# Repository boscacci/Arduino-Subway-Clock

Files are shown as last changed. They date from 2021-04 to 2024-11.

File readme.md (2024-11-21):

# You're about to make your own MTA clock!

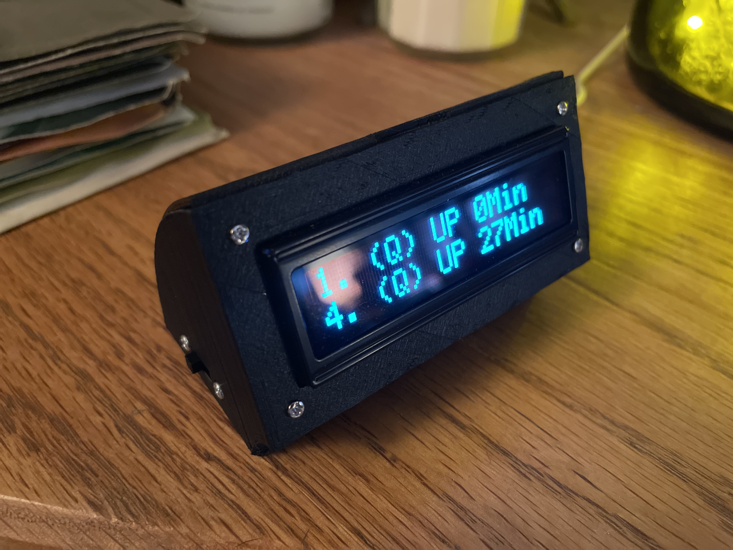
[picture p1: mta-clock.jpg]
Esp32 MTA Clock


Here's how to do it:
1. Host a server (to translate the complex MTA API into something more RESTful).
2. Put and run MTA API code on the server.
3. Buy parts.
4. Wire it up.
5. Install some software.
6. Set up your Arduino project.
7. Edit your MTA Clock preferences.
8. Compile and upload the code.
9. Make an enclosure.
10. Assemble.
11. Don't miss your train!

# 1. Host a server.

  * Recommended: Launch a cloud linux instance, e.g. Ubuntu on AWS. (More [verbose instructions here](https://docs.aws.amazon.com/AWSEC2/latest/UserGuide/EC2_GetStarted.html])
  * Configure the instance's network (and security) settings such that it can respond to requests from wherever the subway clock will be.
  * Connect to your server over SSH.
      
# 3. Put and run MTA API code on the server.

  * Put the MTA API code on the server by cloning from git repo.
  * Use this command in terminal while controlling your server: `git clone https://github.com/jonthornton/MTAPI`
  * cd into the repo top-level directory: `cd MTAPI/`
  * Update your Ubuntu server so it can install stuff: `sudo apt-get update && sudo apt-get upgrade`
  * Install python on your server: `sudo apt-get install python3-venv`
  * Create a new python virtual environment: `python3 -m venv .venv`
  * Create a new tmux session (allowing the code to run unattended): `tmux new -s session-name`
  * Activate the virtual environment: `source .venv/bin/activate`
  * Install necessary python libraries: `pip install -r requirements.txt`
  * Launch the service and begin listening for requests: `python app.py`
  * Detach from the tmux session: ctrl-b, then press d key
  * Disconnect from the ec2 server: `logout`
  * It should be running on its own now!

# 4. Buy parts.

  These are the parts you will need and some examples of where to find them:
  * ESP32 Dev Board (any ESP dev board will do) - https://www.amazon.com/HiLetgo-ESP-WROOM-32-Development-Microcontroller-Integrated/dp/B0718T232Z
  
  * LCD Screen (16x2 Character Display)- https://www.adafruit.com/product/823 - if they're not available through adafruit, try amazon or aliexpress for other 'standard' HD44780 1602 LCDs.
  
  * On/Off Switch (this is just the one we used) - https://www.amazon.com/Qiying-Miniature-SS-12F16-Position-Latching/dp/B08947137H
  
  * Jumperwires
  
  * USB Cable

  Total cost estimate: ~$50-80 depending on parts availability

# 5. Wire it up.

  __Adafruit OLED Wiring Guide:__

  | OLED pin    | ESP32 pin     |
  | :------------- | :------------- |
  |  1 (gnd)    |     GND         |
  |  2 (vin)    |     VIN         |
  |  4 (rs)     |     14          |
  |  5 (rw)     |     32          |
  |  6 (en)     |     26          |
  | 11 (d4)     |     33          |
  | 12 (d5)     |     27          |
  | 13 (d6)     |     12          |
  | 14 (d7)     |     13          |

   * If your ESP32 has different pins labeled, feel free to swap out pins per this pinout guide, but also update line 24 `Adafruit_CharacterOLED lcd(OLED_V2, 14, 32, 26, 33, 27, 12, 13);` in the mta_clock.ino accordingly: https://randomnerdtutorials.com/esp32-pinout-reference-gpios/

   * Optional: Connect, an on/off switch between ESP32 pin 25 (or any other digital pin) and GND.

# 6. Install some software.

## 6.1 Install ArduinoIDE.

  * Download and install the ArduinoIDE from here: https://www.arduino.cc/en/software

## 6.2 Install ESP board in Arduino.

  * Open ArduinoIDE
  * Copy the URL found at this git: https://github.com/espressif/arduino-esp32/blob/master/docs/arduino-ide/boards_manager.md
  * In ArduinoIDE, paste to File > Preferences > Additional Board Manager URLs
  * Open Boards Manager from Tools > Board menu
  * Search for "esp32" and Install
  * Select your particular ESP32 board from Tools > Board menu

## 6.3 Install necessary libraries.

  * Open Library Manager from Tools > Manage Libraries...
  * Search for "Arduino_JSON" and Install
  * Download ZIP from here: https://github.com/ladyada/Adafruit_CharacterOLED
  * Add the library to Arduino from Sketch > Include Library > Add .ZIP Library...

# 7. Set up your Arduino project.

  * If you haven't already, download the ZIP of this Git Repo.
  * Move the folder "mta_clock" from the ZIP folder into your Sketchbook folder.
  * If you don't know where that is, it is listed at File > Preferences > Sketchbook location

# 8. Edit your MTA Clock preferences.

  * Open the mta_clock.ino sketch from File > Sketchbook > mta_clock
  * Go to the preferences.h tab.
  * Replace the default with your Wifi network info, server IP (found in your EC2 instances, use the IPv4 address), and other preferred settings. [You can find the codes for StationID's here](https://github.com/boscacci/MTAPI/blob/master/data/stations.json).
  * Save your changes.

# 9. Compile and upload the code.

  * Connect the ESP32 to the computer with the USB cable.
  * Ensure that the correct port is selected at Tools > Port > /dev/cu.usbserial*
  * Ensure that Tools > Upload Speed is set to 115200
  * Click the check mark to "Verify" (a.k.a. Compile) the code.
  * Click the => to upload the code to your ESP32.
  * Wait.... this will probably take a minute or two.
  * When it's done uploading, you can open the Serial monitor (set to Baud rate: 115200) with the magnifying glass button to see how it's doing.

  NOTE: For some reason, the LCD might not display properly while the serial monitor window is open.

  ANOTHER NOTE: The LCD won't reset when the ESP32 resets, so you might have to unplug and replug the usb cable to get it to display properly.

# 10. Make an enclosure.

  * You can buy something like this: https://www.amazon.com/CANADUINO-Character-Display-Acrylic-Enclosure/dp/B07C4XWX21

  NOTE: It did not fit my display and there isn't a great way to mount the ESP32.

  * Alternatively, you can 3D print the enclosure found in the git.
    To avoid supports:
    * Print main_enclosure_switch.stl or main_enclosure_noswitch.stl lcd-face down
    * Print enclosure_cover.stl on one end - the little tabs are tapered on one edge more than the other and that should face down.

# 11. Assemble.

  If you're happy with your preferences, and everything fits properly in the enclosure, you can solder the connections and install everything in the enclosure.

# 12. Don't miss your train!

  If you're still reading, thanks for reading me. Now, credit where credit is due! Thanks to:

  Zach Kuperstein for toiling in an unfamiliar language to make this, and making the instructions as clear as possible!

  Jon Thornton for making the MTA's GTFS protobuf accessible.

  Bill & George at NYC Resistor for making the first generation version of this.

  The MTA for making its data available to the public.

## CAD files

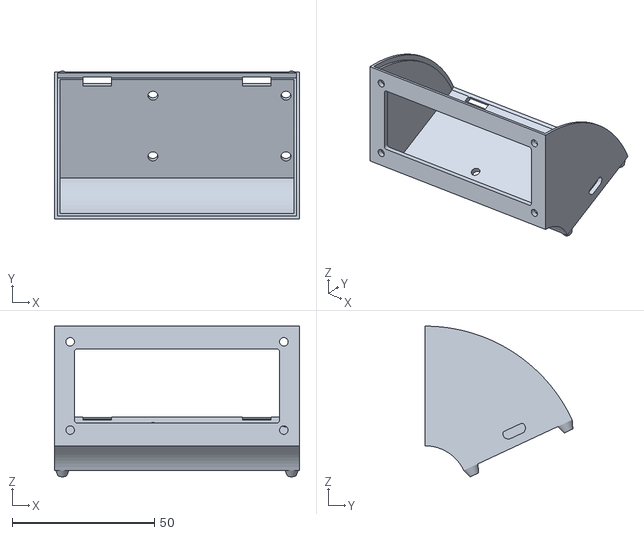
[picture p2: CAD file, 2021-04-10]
3d print files/main_enclosure_noswtich.stl
86.0 x 51.9 x 52.9

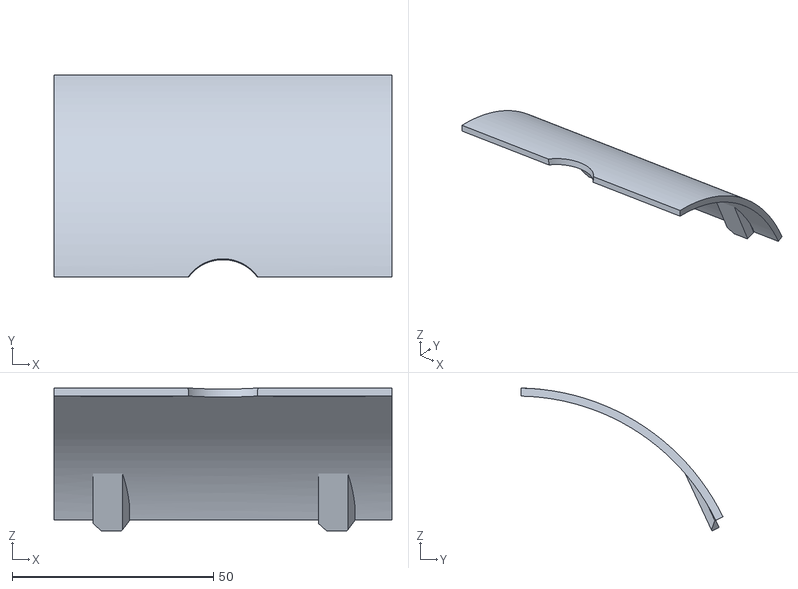
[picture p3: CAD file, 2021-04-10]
3d print files/enclosure_cover.stl
84.0 x 50.2 x 35.5

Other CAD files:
3d print files/main_enclosure_switch.stl

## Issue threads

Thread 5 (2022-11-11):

This is not an issue, just a question!

fixingthingsguy, 2022-11-11:
Hello Robert, Great job with the application. Not much of a modern techie, but wondering what the purpose of the AWS EC2 set  up was for.
Basically I'm wondering if the MTA feed can't be received at the ESP. There are other feeds, probably for sure not as complex, that ESP can receive, for example weather underground.
So I was looking to see if that kind of model would work.
Thanks, again, great job.
I'll delete this in a couple of days since its not a fair "issue:".
Regards

fixingthingsguy, 2022-11-27:
Not really an issue, so closing as promised.

boscacci, 2022-11-27:
Hi there, thanks for asking.

Programmers better than me have succeeded at parsing the MTA protobuf feed directly on the ESP32. I am not among their ranks.

Instead, here we used MTAPI (hosted on an ec2 instance, but could be hosted anywhere I guess) to translate the MTA protobuf feed into something more RESTful which the ESP32 could query more easily.

fixingthingsguy, 2022-11-29:
Hi Robert Thanks for rhe explanation. I had seen some  very complex approaches on the internet alluding to what you said.Anyway, I'm marching along the steps you provided . The ESP I'm familar with, and I think I can figure out the EC2 implementation, with a few attempts and re-do's.Thanks for taking the trouble to post your solution.

Sent from Yahoo Mail on Android

  On Sun, Nov 27, 2022 at 2:23 PM, Robert ***@***.***> wrote:

Hi there, thanks for asking.

Programmers better than me have succeeded at parsing the MTA protobuf feed directly on the ESP32. I am not among their ranks.

Instead, here we used MTAPI (hosted on an ec2 instance, but could be hosted anywhere I guess) to translate the MTA protobuf feed into something more RESTful which the ESP32 could query more easily.

—
Reply to this email directly, view it on GitHub, or unsubscribe.
You are receiving this because you modified the open/close state.Message ID: ***@***.***>

Closed 2022-11-27.

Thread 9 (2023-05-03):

Compilation error: 'JSONVar' was not declared in this scope

thagoober, 2023-05-03:
Hello,

I've followed your instructions and am really excited to have this working, it's been a fantastic beginner project for me to learn.

However, I'm struggling with this line of code that is producing an odd error I haven't been able to figure out.. Would you happen to have any insight why I'm getting this error on upload?

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

thagoober, 2023-05-03:
Nevermind, I've figured out there was a probem with the json library installation. Thanks!

Closed 2023-05-03.

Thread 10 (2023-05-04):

Watchdog timer issue with esp32?

thagoober, 2023-05-04:
I am having a hell of a time sorting through this one, and even had ChatGPT make some sense of this for me, but once I upload the code to the esp32, it gives me this message in the Output:

Leaving...
Hard resetting via RTS pin...

Followed by this recurring error (in 10s intervals) in the Serial Monitor (which looks like a watchdog timer issue due to a loop in the code):

rst:0x10 (RTCWDT_RTC_RESET),boot:0x13 (SPI_FAST_FLASH_BOOT)
configsip: 0, SPIWP:0xee
clk_drv:0x00,q_drv:0x00,d_drv:0x00,cs0_drv:0x00,hd_drv:0x00,wp_drv:0x00
mode:DIO, clock div:2
load:0x3fff0030,len:1344
load:0x40078000,len:13808
load:0x40080400,len:3608
entry 0x400805f0

May I ask your advice on this?

thagoober, 2023-05-04:
Holy smokes I figured it out.. I needed to connect a 3.3v + ground connection to the VSS/VDD side of the OLED, while also connecting 5v+ground as indicated. This solves the issue with the OLED loop in the code getting timed out by the watchdog timer.

boscacci, 2023-05-27:
Nicely done sorry for the delayed response

Closed 2023-05-04.

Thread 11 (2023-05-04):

Issue with OLED library

thagoober, 2023-05-04:
Be sure to change the entry in the OLED library from "void begin(uint8_t cols, uint8_t rows, uint8_t character_set = LCD_JAPANESE);" to "void begin(uint8_t cols, uint8_t rows, uint8_t character_set /*= LCD_JAPANESE*/);"

Needs /* */ or the code will not compile correctly in Arduino IDE.

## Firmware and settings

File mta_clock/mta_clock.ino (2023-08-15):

// include the library code:
#include <Adafruit_CharacterOLED.h>
#include <WiFi.h>
#include <HTTPClient.h>
#include <Arduino_JSON.h>
#include "time.h"
#include "preferences.h" //file containing User preferences

/*
  Adafruit OLED Wiring Guide (https://www.adafruit.com/product/823):

   OLED pin  <-->   ESP32 pin
    1 (gnd)         GND
    2 (vin)         VIN
    4 (rs)          14
    5 (rw)          32
    6 (en)          26
   11 (d4)          33
   12 (d5)          27
   13 (d6)          12
   14 (d7)          13

*/
Adafruit_CharacterOLED lcd(OLED_V2, 14, 32, 26, 33, 27, 12, 13);

#define SWITCH_PIN 25 // sets pin for direction toggle switch connect other end to GND

// This defines the direction variable differently depending on if you are using a toggle switch
#ifndef DIRECTION
char *direction = "N";
#else
const char *direction = DIRECTION;
#endif

// Declaring global variables
unsigned long lastRequestTime = 0;
unsigned long lastDisplayTime = 0;
time_t currentEpochTime;
struct tm currentTime;
char display[20];
char displayList[8][20];
byte listCount = 1;
bool forceRefresh = true;
bool switchState = true;
char url[sizeof(serverIP) + sizeof(stationID) + 19];
byte numberOfArrivals;

void setup()
{
  Serial.begin(115200);
  while (!Serial)
    ;

  Serial.println("Initializing...");

  // Sets up toggle switch pin with internal pullup resistor
  pinMode(SWITCH_PIN, INPUT_PULLUP);

  // Initialize the lcd
  Serial.print("LCD - ");
  lcd.begin(16, 2);
  Serial.println("LCD success!");

  // Connect to the WiFi network
  connectWifi();

  // Configure DST-aware datetime for NYC
  initTime("EST5EDT,M3.2.0,M11.1.0");

  Serial.print("Local time: ");
  printLocalTime();
  Serial.println(" - Success!");

  // Make url for MTA data request
  sprintf(url, "http://%s:8080/by-id/%s", serverIP, stationID);

  delay(1000);
  lcd.clear();
}

void loop()
{
// If you have a direction toggle switch this function handles it
#ifndef DIRECTION
  switchHandler();
#endif

  // Send an HTTP GET request every time interval
  if (forceRefresh || (millis() - lastRequestTime) > requestInterval)
  {

    // Check WiFi connection status
    if (WiFi.status() == WL_CONNECTED)
    {

      // gets current local time in epoch and tm format respectively
      time(&currentEpochTime);
      getLocalTime(&currentTime);

      // Make server request and parse into JSON object
      JSONVar obj = JSON.parse(httpGETRequest(url));

      // JSON.typeof(jsonVar) can be used to get the type of the var
      if (JSON.typeof(obj) == "undefined")
      {
        Serial.println("Parsing input failed!");
        return;
      }

      // Pulls out the relevant data as an JSONVar array
      JSONVar arrivalsArr = obj["data"][0][direction];
      numberOfArrivals = arrivalsArr.length();

      // Initiate a count of arrivals that will be missed per timeToStation
      byte missed = 0;

      // Clear the displayList
      memset(&displayList, 0, sizeof(displayList));

      // Iterates through each pending arrival
      for (byte i = 0; i < numberOfArrivals; i++)
      {

        // Extracts the name of the train for the given arrival
        String trainName = JSON.stringify(arrivalsArr[i]["route"]).substring(1, 2);

        // Extracts the arrival time of the train in epoch time

        // DEBUG
        // Serial.print("Arrival time stringified: ");
        // Serial.println(JSON.stringify(arrivalsArr[i]["time"]));

        long arrivalTime = convertToEpoch(JSON.stringify(arrivalsArr[i]["time"]));

        // Calculates how many minutes to arrival by comparing arrival time to current time
        int minutesAway = (arrivalTime - currentEpochTime) / 60;

        // Filters out trains that you can't possibly catch
        if (minutesAway >= timeToStation)
        {

          // Constructs the display string
          sprintf(display, "%d. (%s) %s %dMin", i + 1 - missed, trainName, (direction == "N") ? "UP" : "DN", minutesAway);
          Serial.println(display);

          // Adds the given arrival to the display list for the lcd
          strcpy(displayList[i - missed], display);
        }
        else
        {
          missed++; // increment count of missed trains per timeToStation
        }
      }

      // Display the next arriving train on the first line of the lcd
      lcd.setCursor(0, 0);
      lcd.print("                "); // needed to clear the first line
      lcd.setCursor(0, 0);
      lcd.print(displayList[0]);
    }
    else
    {
      Serial.println("WiFi Disconnected");
      delay(1000);
      connectWifi();
    }
    lastRequestTime = millis();
  }

  // Rotate the arrival displayed on the second line at specified time interval
  if (forceRefresh || (millis() - lastDisplayTime) > displayInterval)
  {

    lcd.setCursor(0, 1);
    lcd.print("                "); // needed to clear the line if the previous display was longer
    lcd.setCursor(0, 1);
    lcd.print(displayList[listCount]);

    listCount++;
    if (listCount > moreArrivals || listCount >= numberOfArrivals)
      listCount = 1;

    lastDisplayTime = millis();

    forceRefresh = false;
  }
}

void connectWifi()
{
  Serial.print("Connecting to Wifi: ");
  Serial.print(ssid);

  lcd.clear();
  lcd.setCursor(0, 0);
  lcd.print("Joining Wifi");
  lcd.setCursor(0, 1);
  lcd.print(ssid);

  WiFi.begin(ssid, password);

  while (WiFi.status() != WL_CONNECTED)
  {
    delay(500);
    Serial.print(".");
    lcd.print(".");
  }

  lcd.setCursor(0, 0);
  lcd.print("Connected to:");
  Serial.println("Success!");
  Serial.print("IP address: ");
  Serial.println(WiFi.localIP());
}

String httpGETRequest(char *_url)
{
  HTTPClient http;

  Serial.print("Pinging: ");
  Serial.println(_url);

  // Connect to server url
  http.begin(_url);

  // Send HTTP GET request
  byte httpResponseCode = http.GET();

  if (httpResponseCode == 200)
  {
    Serial.print("Updated: ");
    Serial.println(&currentTime);
    return http.getString();
  }
  else
  {
    Serial.print("HTTP Error code: ");
    Serial.println(httpResponseCode);

    lcd.clear();
    lcd.setCursor(0, 0);
    lcd.print("HTTP ERROR: ");
    lcd.print(httpResponseCode);
    lcd.setCursor(0, 1);
    lcd.print("SERVER DOWN");
    delay(1000);
  }
}

bool isDST(const String &dateTime)
{
  if (dateTime.endsWith("-04:00\""))
  {
    return true;
  }
  else if (dateTime.endsWith("-04:00"))
  {
    return true;
  }
  return false;
}

// Manually parses the timeStamp from the train arrival and returns in epoch time
long convertToEpoch(String timeStamp)
{
  struct tm t;
  memset(&t, 0, sizeof(tm));                            // Initalize to all 0's
  t.tm_year = timeStamp.substring(1, 5).toInt() - 1900; // This is year-1900, so 112 = 2012
  t.tm_mon = timeStamp.substring(6, 8).toInt() - 1;     // It has -1 because the months are 0-11
  t.tm_mday = timeStamp.substring(9, 11).toInt();
  t.tm_hour = timeStamp.substring(12, 14).toInt();
  t.tm_min = timeStamp.substring(15, 17).toInt();
  t.tm_sec = timeStamp.substring(18, 20).toInt();

  // Run a check to see if MTA arrival times are DST or not
  bool dst = isDST(timeStamp);
  t.tm_isdst = dst;
  // Debug:
  // Serial.println(dst ? "It is DST" : "It is not DST");

  time_t epoch = mktime(&t);
  return epoch;
}

// Function to handle direction toggle switch
#ifndef DIRECTION
void switchHandler()
{
  // toggles with switch
  if (digitalRead(SWITCH_PIN) != switchState)
  {
    switchState = !switchState;

    // Sets direcdtion per the switch state
    if (switchState)
      direction = "N";
    else
      direction = "S";

    // Notifies in serial monitor
    Serial.print("Direction: ");
    Serial.println(direction);

    // Notifies on LCD screen
    lcd.clear();
    lcd.setCursor(0, 0);
    lcd.print("Direction set: ");
    lcd.print(direction);
    delay(1000);

    // Forces refresh on the next loop
    forceRefresh = true;
  }
}
#endif

void setTimezone(String timezone)
{
  Serial.printf("  Setting Timezone to %s\n", timezone.c_str());
  setenv("TZ", timezone.c_str(), 1); //  Now adjust the TZ.  Clock settings are adjusted to show the new local time
  tzset();
}

void initTime(String timezone)
{
  struct tm timeinfo;
  Serial.println("Setting up time");
  configTime(0, 0, "pool.ntp.org"); // First connect to NTP server, with 0 TZ offset
  if (!getLocalTime(&timeinfo))
  {
    Serial.println("  Failed to obtain time");
    return;
  }
  Serial.println("  Got the time from NTP");
  // Now we can set the real timezone
  setTimezone(timezone);
}

void printLocalTime()
{
  struct tm timeinfo;
  if (!getLocalTime(&timeinfo))
  {
    Serial.println("Failed to obtain time");
    return;
  }
  Serial.println(&timeinfo, "%A, %B %d %Y %H:%M:%S zone %Z %z ");
}

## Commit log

2021-04-10 Init repo
    [enclosure_cover.stl, main_enclosure_noswtich.stl, main_enclosure_switch.stl]
2021-04-11 Added comment about wifi types with ESP32
2021-04-11 Stopgap fix for weird data type behavior
    [mta_clock.ino]
2021-04-12 fixed minutesAway, removed missed
    [mta_clock.ino]
2023-05-10 WIP switch to new API
